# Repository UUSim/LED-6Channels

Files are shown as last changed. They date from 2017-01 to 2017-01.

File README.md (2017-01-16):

# 6 Channel LED controller board
This project hosts the Eagle-based design of a 6 channel LED controller.

The device features:
- DC power (rated 7-12V)
- Powered via i2c bus connector (TBD)
- Controlled via 3 rotary encoders:
  - Intensity for 2 separate LED sections
  - One color wheel
- Clock with battery backup
- Programming header
- External i2c-bus connector

The 6 channels are configured as follows:
- 1 RGB connector
- 3 separate connectors for a color of choice

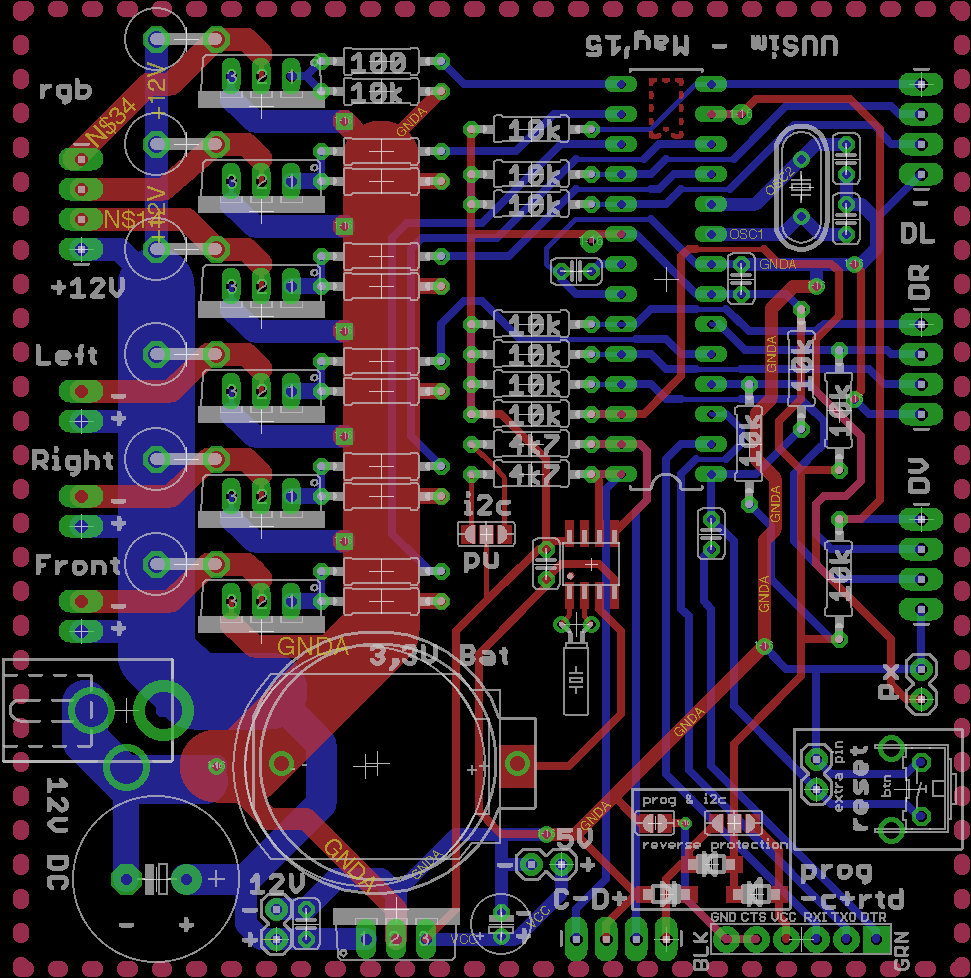
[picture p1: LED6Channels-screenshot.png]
Screenshot of board layout

Note: The board is layed out such that diy etching is possible using double-sided UV-lighting and etching. The traces are routed such that the number of vias is kept to a minimum (avoiding trough-hole plating).

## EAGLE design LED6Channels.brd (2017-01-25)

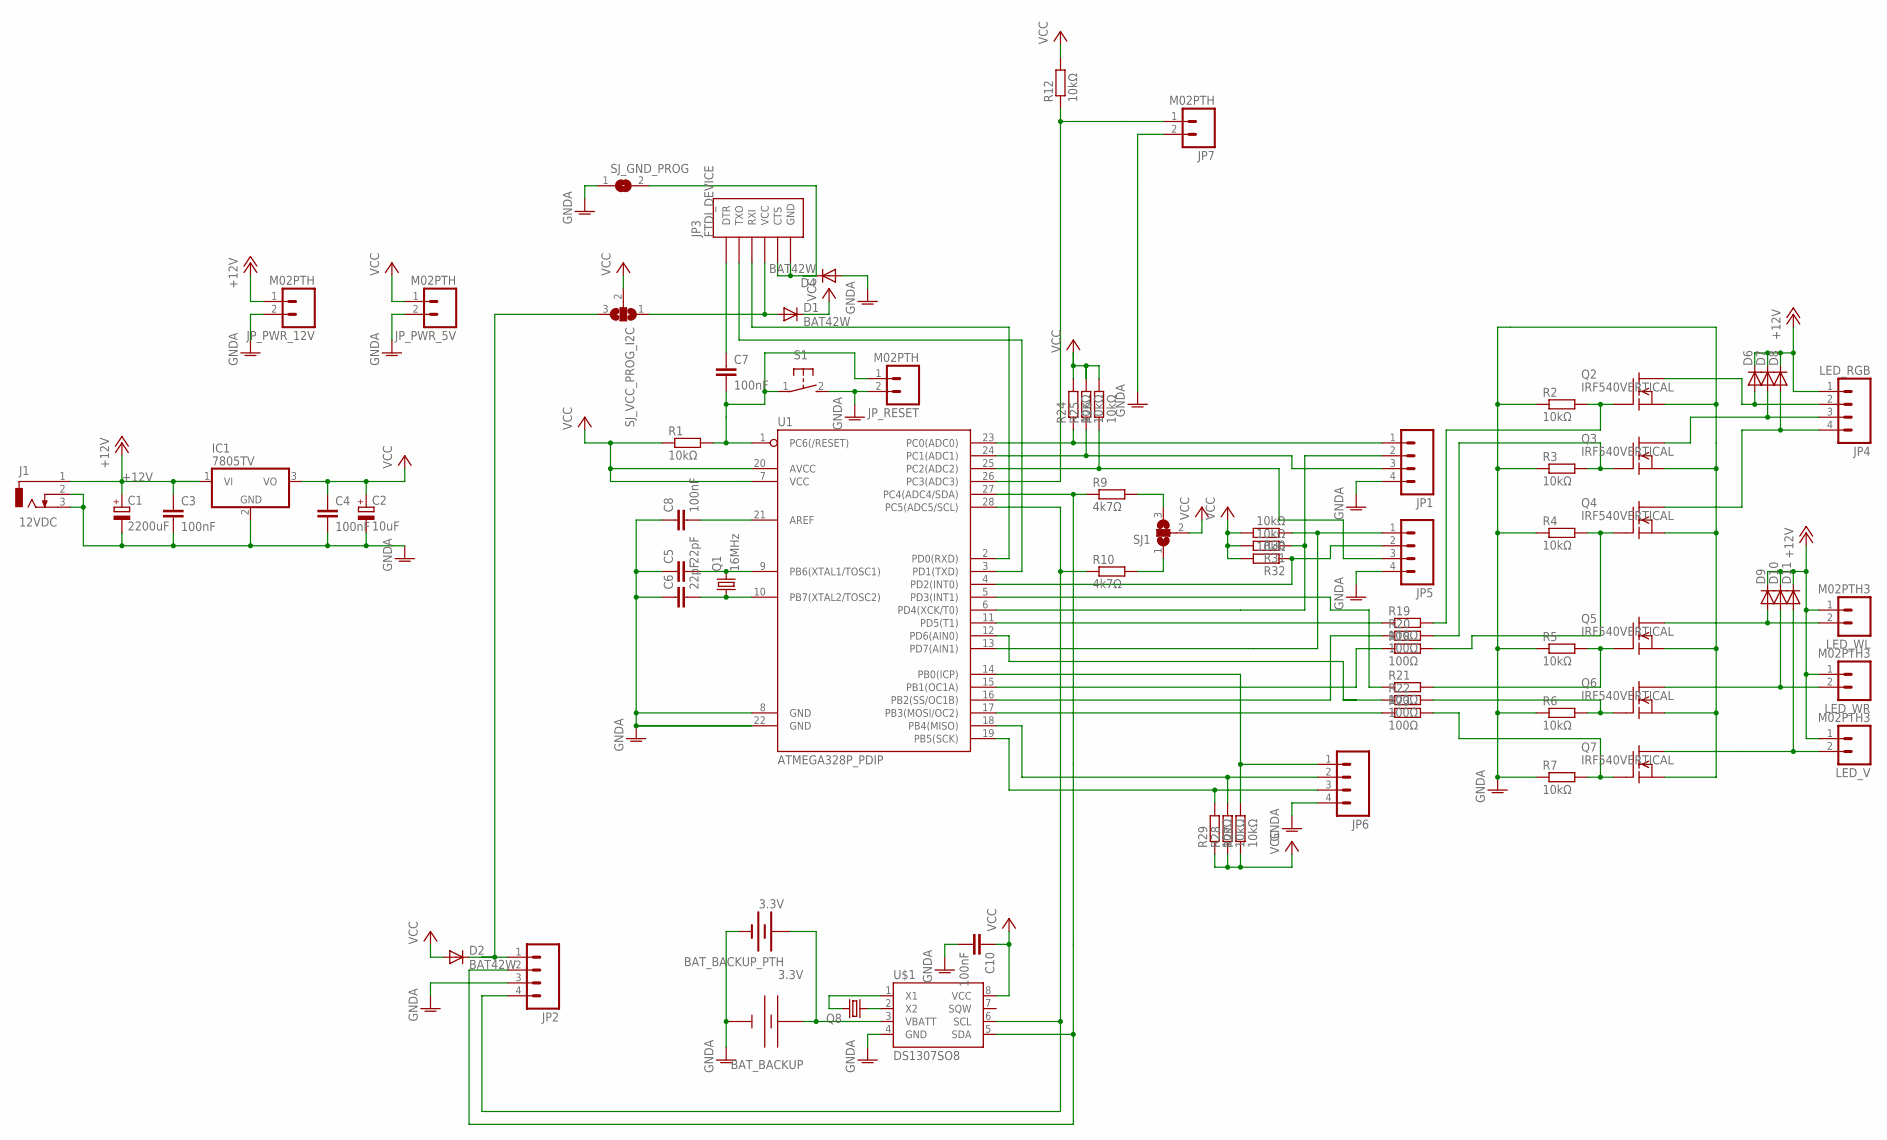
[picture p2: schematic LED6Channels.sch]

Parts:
BAT_BACKUP: 3.3V; S8421-45R-NOVIAS
BAT_BACKUP_PTH: 3.3V; BATTCOM_20MM_PTH
C1: 2200uF; E5-13
C2: 10uF; E2-5
C3, C4, C7, C8, C10: 100nF; C025-024X044
C5, C6: 22pF; C025-024X044
D1, D2, D4: BAT42W; SOD123
D6, D7, D8, D9, D10, D11: DIODE-DO201-05V; DO201AD-05V
IC1: 7805TV; TO220V
J1: 12VDC; DCJ0303
JP1, JP2, JP5, JP6: M04LONGPADS; 1X04_LONGPADS
JP3: FTDI_DEVICE; FTDI_DEVICE_SIDE
JP4: LED_RGB; 1X04_LONGPADS
JP7: M02PTH; 1X02
JP_PWR_5V, JP_PWR_12V: M02PTH; 1X02
JP_RESET: M02PTH; 1X02
LED_V: M02PTH3; 1X02_LONGPADS
LED_WL: M02PTH3; 1X02_LONGPADS
LED_WR: M02PTH3; 1X02_LONGPADS
Q1: 16MHz; HC49/S
Q2, Q3, Q4, Q5, Q6, Q7: IRF540VERTICAL; TO220V
Q8: CRYSTALTC26H; TC26H
R1, R2, R3, R4, R5, R6, R7, R12, R24, R25, R26, R27, R28, R29, R30, R31, R32: 10kΩ; 0207/10
R9, R10: 4k7Ω; 0207/10
R18, R19, R20, R21, R22, R23: 100Ω; 0207/10
S1: 31-XX; B3F-31XX
SJ1: SJ2W; SJ_2
SJ_GND_PROG: SJ
SJ_VCC_PROG_I2C: SJ2W; SJ_2
U1: ATMEGA328P_PDIP; DIL28-3
U$1: DS1307SO8; SO08

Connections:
+12V: C1.+, C3.1, D6.C, D7.C, D8.C, D9.C, D10.C, D11.C, IC1.1 (VI), J1.1, JP4.1, JP_PWR_12V.1, LED_V.1, LED_WL.1, LED_WR.1
E1_BUTTON: JP1.3, R25.1, U1.24 (PC1(ADC1))
E1_L: JP1.1, R24.1, U1.23 (PC0(ADC0))
E1_R: JP5.3, R26.1, U1.25 (PC2(ADC2))
E2_BUTTON: JP1.2, R31.1, U1.6 (PD4(XCK/T0))
E2_L: JP5.2, R32.1, U1.4 (PD2(INT0))
E2_R: JP5.1, R30.1, U1.13 (PD7(AIN1))
GNDA: BAT_BACKUP.2 (-), BAT_BACKUP_PTH.2 (-), C1.-, C2.-, C3.2, C4.2, C5.1, C6.1, C8.1, C10.2, D4.A, IC1.2 (GND), J1.2, J1.3, JP1.4, JP2.3, JP5.4, JP6.4, JP7.2, JP_PWR_5V.2, JP_PWR_12V.2, JP_RESET.2, Q2.3 (S), Q3.3 (S), Q4.3 (S), Q5.3 (S), Q6.3 (S), Q7.3 (S), R2.1, R3.1, R4.1, R5.1, R6.1, R7.1, S1.2 (S), SJ_GND_PROG.1, U1.8 (GND), U1.22 (GND), U$1.4 (GND)
unnamed: Q7.1 (G), R7.2, R23.2
unnamed: R23.1, U1.17 (PB3(MOSI/OC2))
unnamed: Q6.1 (G), R6.2, R22.2
unnamed: R20.1, U1.16 (PB2(SS/OC1B))
unnamed: R18.1, U1.15 (PB1(OC1A))
unnamed: R21.1, U1.5 (PD3(INT1))
unnamed: Q3.1 (G), R3.2, R20.2
unnamed: Q2.1 (G), R2.2, R19.2
unnamed: D10.A, LED_WR.2, Q6.2 (D)
unnamed: D9.A, LED_WL.2, Q5.2 (D)
unnamed: D11.A, LED_V.2, Q7.2 (D)
unnamed: D6.A, JP4.2, Q2.2 (D)
unnamed: D7.A, JP4.3, Q3.2 (D)
unnamed: C8.2, U1.21 (AREF)
unnamed: JP6.2, R28.2, U1.18 (PB4(MISO))
unnamed: JP6.3, R29.2, U1.19 (PB5(SCK))
unnamed: JP6.1, R27.2, U1.14 (PB0(ICP))
unnamed: Q5.1 (G), R5.2, R21.2
unnamed: R19.1, U1.11 (PD5(T1))
unnamed: R22.1, U1.12 (PD6(AIN0))
unnamed: Q4.1 (G), R4.2, R18.2
unnamed: D8.A, JP4.4, Q4.2 (D)
OSC1: C5.2, Q1.2, U1.9 (PB6(XTAL1/TOSC1))
OSC2: C6.2, Q1.1, U1.10 (PB7(XTAL2/TOSC2))
PIN_EXTRA: JP7.1, R12.1, U1.26 (PC3(ADC3))
P_GND: D4.C, JP3.P$5 (CTS), JP3.P$6 (GND), SJ_GND_PROG.2
P_RESET: C7.1, JP3.P$1 (DTR)
P_RX: JP3.P$3 (RXI), U1.2 (PD0(RXD))
P_TX: JP3.P$2 (TXO), U1.3 (PD1(TXD))
P_VCC: D1.A, JP3.P$4 (VCC), SJ_VCC_PROG_I2C.1
RESET: C7.2, JP_RESET.1, R1.2, S1.1, U1.1 (PC6(/RESET))
SCL: JP2.4, R10.1, U1.28 (PC5(ADC5/SCL)), U$1.6 (SCL)
SCL_PULLUP_JUMP: R10.2, SJ1.1
SDA: JP2.2, R9.1, U1.27 (PC4(ADC4/SDA)), U$1.5 (SDA)
SDA_PULLUP_JUMP: R9.2, SJ1.3
VBAT: BAT_BACKUP.1 (+), BAT_BACKUP_PTH.1 (+), U$1.3 (VBATT)
VCC: C2.+, C4.1, C10.1, D1.C, D2.A, IC1.3 (VO), JP_PWR_5V.1, R1.1, R12.2, R24.2, R25.2, R26.2, R27.1, R28.1, R29.1, R30.2, R31.2, R32.2, SJ1.2, SJ_VCC_PROG_I2C.2, U1.7 (VCC), U1.20 (AVCC), U$1.8 (VCC)
VCC_I2C: D2.C, JP2.1, SJ_VCC_PROG_I2C.3
X1: Q8.2, U$1.1 (X1)
X2: Q8.1, U$1.2 (X2)

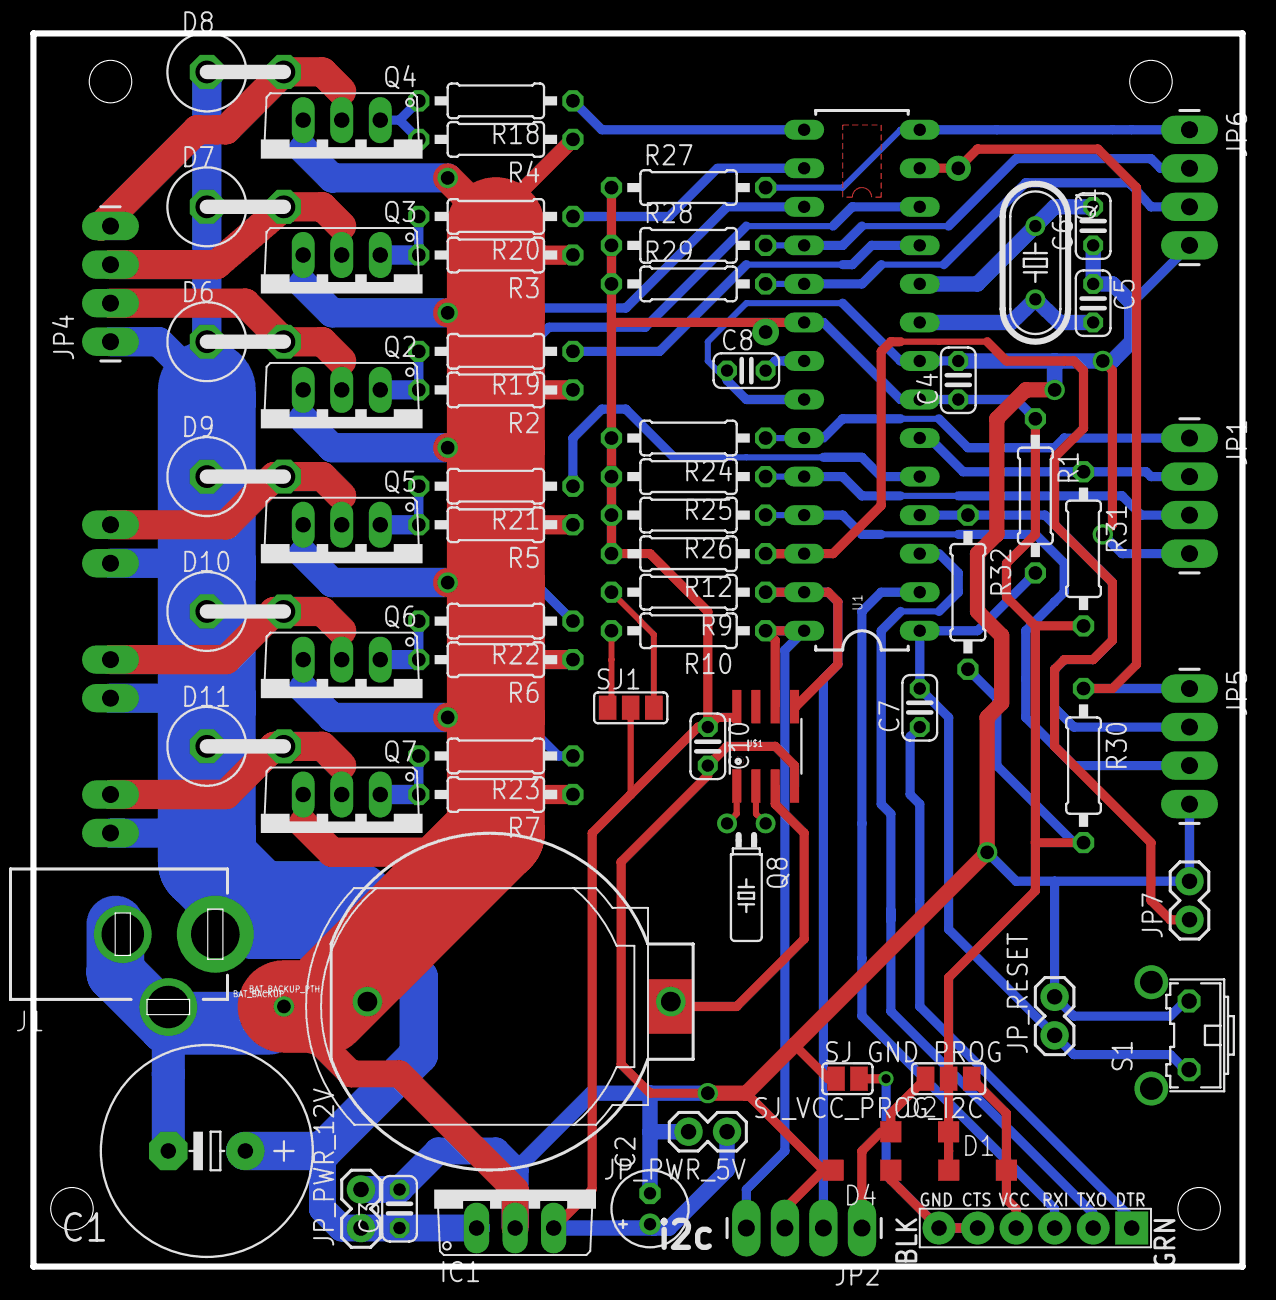
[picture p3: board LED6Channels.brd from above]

Board: 2 copper layers, 79.7 x 81.3 mm, 74 parts (0 on the bottom side), 48 nets.

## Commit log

2017-01-16 Added screenshot of board layout
2017-01-25 Added Eagle design files
    Added schematic and board files
    [LED6Channels.brd, LED6Channels.sch]

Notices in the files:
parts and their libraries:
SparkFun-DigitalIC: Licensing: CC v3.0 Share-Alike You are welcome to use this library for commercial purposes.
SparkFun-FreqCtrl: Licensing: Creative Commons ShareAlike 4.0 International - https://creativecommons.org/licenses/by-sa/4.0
